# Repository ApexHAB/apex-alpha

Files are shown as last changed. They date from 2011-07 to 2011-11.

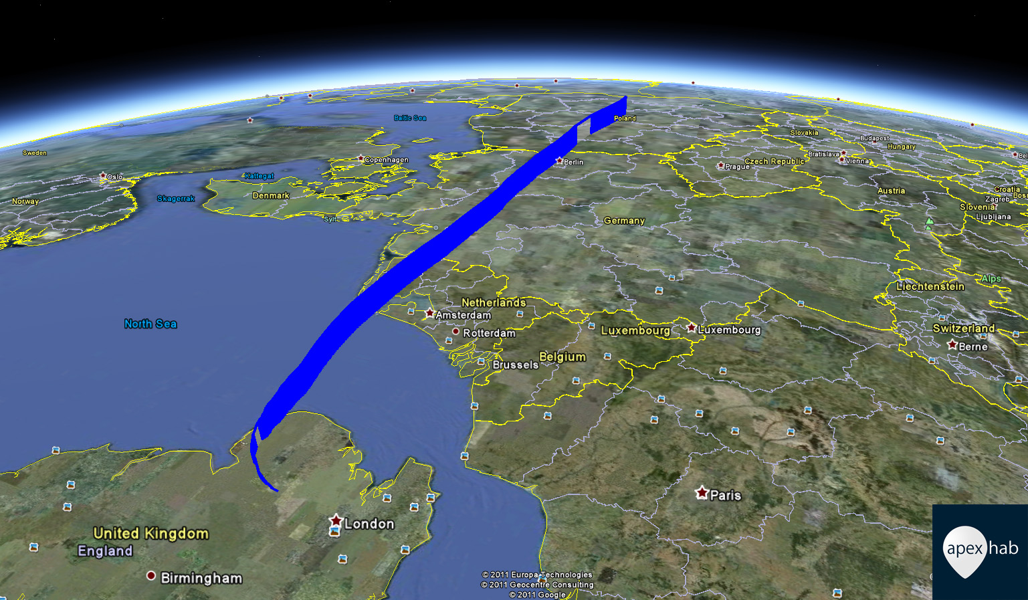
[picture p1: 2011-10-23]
launches/launch-1/maps+graphs/track-3.jpg

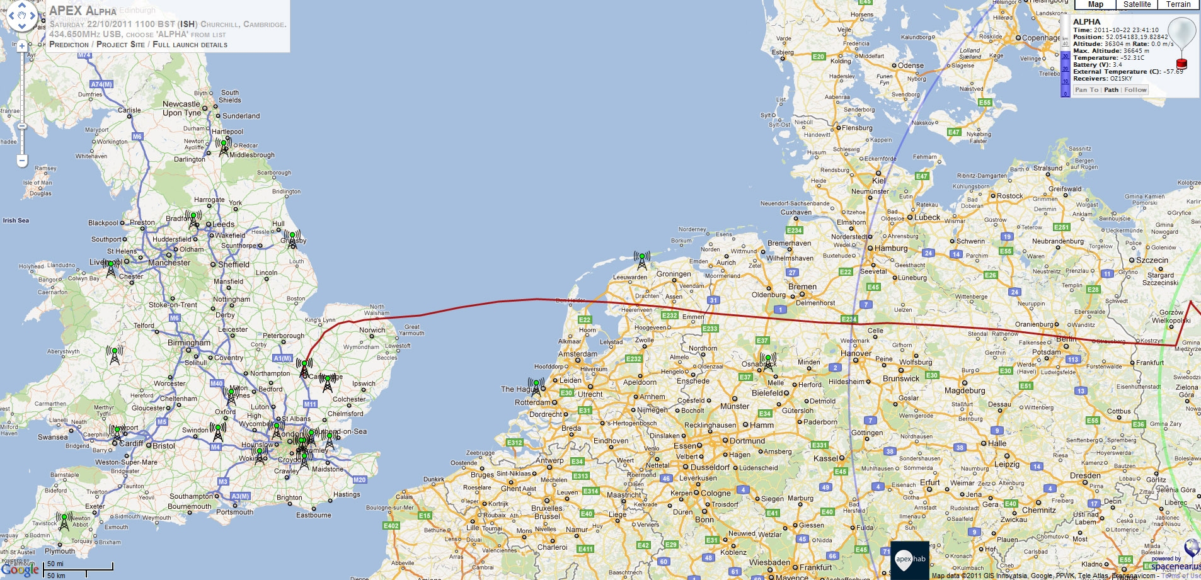
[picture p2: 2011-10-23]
launches/launch-1/maps+graphs/map-2.jpg

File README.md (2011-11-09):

# Apex Alpha
## A small, light-weight payload which will be the predecessor to Apex III

Apex Alpha is a small, light payload which will lead to the development of Apex III. The payload is based around the AVR micro-controllers with the Arduino bootloader. With a completely redesigned payload, we hope that Apex Alpha will be able to help us break records and move the project forward towards Apex III.  Apex Alpha was launched on 22nd October 2011.

## Useful links

* [Homepage](http://www.apexhab.org) - http://www.apexhab.org
* [Apex Alpha Homepage](http://www.apexhab.org/alpha/) - http://www.apexhab.org/alpha/
* [Contact](mailto:team@apexhab.org) - team@apexhab.org
* [Twitter](http://twitter.com/apexhab) - http://twitter.com/apexhab

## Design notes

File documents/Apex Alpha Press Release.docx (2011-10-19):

APEX Alpha High Altitude Balloon Launch by Sutton Grammar School for Boys. Saturday 22nd October 2011. Churchill College, Cambridge.

The APEX team is a group of teenagers who are passionate about electronics, technology and engineering.

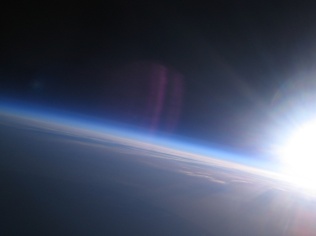
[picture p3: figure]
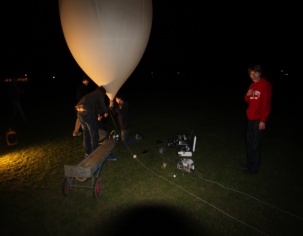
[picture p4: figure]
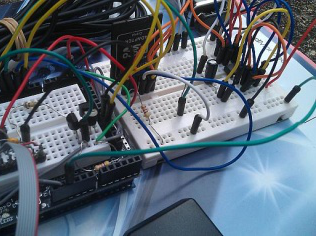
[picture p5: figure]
IMAG0075
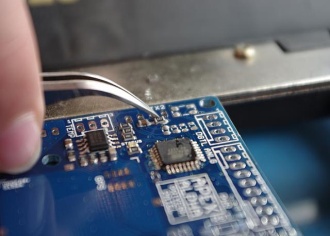
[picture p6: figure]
IMGP1281

Background

The Apex High Altitude Balloon Project aims to use meteorological balloons to take photographs, capture video and collect sensor data from near-space. To date there have been two versions of Apex and three launches in total. On the 22nd October 2011 at 11am there will be a fourth launch with a new, very light payload; the aim is to break the current UK amateur altitude record for a weather balloon flight. Photos of this launch and the team will be available immediately after.

Weather balloons typically reach altitudes of 120,000ft, beyond the troposphere and into the stratosphere; this is 3½ times the altitude of a commercial aeroplane. The ApexHAB team aim to exceed this height and reach 4 times the altitude of a commercial flight.

The Apex High Altitude Balloon Project has been running since September 2008. It is being run by pupils at Sutton Grammar School for Boys. The boys running the project range in age from 15-17 and are named: Priyesh Patel, Daniel Saul, Edward Branford, Philip Warren, Alex Landless, Michael Woodgate and Alex Wakefield.

Launch – Sat 22nd Oct

APEX Alpha, the team’s newest payload will be launched for the first time. Weighing under 275g, it is extremely light with the electronics themselves weighing in at only 36g – sensors on the PCB, designed entirely by the students; include internal and external temperature and GPS co-ordinates and altitude. This data is then relayed to the team via a small radio module which is then picked up on an amateur radio set and fed into a software decoder on the team’s laptops. APEX Alpha is designed to become the core module of our next big payload, APEX III, developed from the ground up to be modular and efficient.

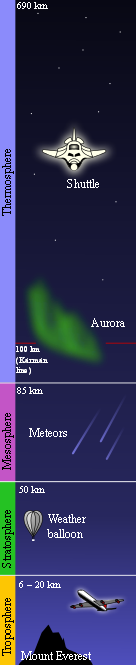
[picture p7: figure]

Funding

The Balloon has been completely self-built by pupils in the school and has been funded by the Institute of Physics, Virgin Galactic, AFCEA (Armed Forces Communications and Electronics Association.), Dorking and District Radio Society, the school’s Curriculum Enrichment Group and the school PTA. The team is once again actively looking for sponsorship.

Previous achievements

Previous launches’ data and photographs are available online at www.apexhab.org including photographs and video footage of sunrise taken above 90,000ft. At this altitude the layers of the Earth’s atmosphere are clearly visible.

Future work

The team will be entering into the National Science and Engineering Competition and hope to gain a place in the finals at the Big Bang Fair in March 2012. There is also another planned launch for Spring 2012 of APEX III carrying instruments capable of measuring radiation levels at varying altitudes, light levels, various gas sensors such as CO2, an ash sensor which could collect interesting data in the event of another volcanic eruption affecting the UK, a pressure sensor, higher resolution cameras and our HD Video Camera.

For more information, please email team@apexhab.org or contact Sutton Grammar School for Boys.

Apex High Altitude Balloon Project press release 19th October 2011 For more information, get in touch at team@apexhab.org

FOR IMMEDIATE RELEASE hab

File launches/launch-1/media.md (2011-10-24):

 * http://ukhas.org.uk/general:flight_data
 * http://ukhas.org.uk/general:uk_records
 * http://hab-howard.blogspot.com/
 * http://arduinoist.com/2011/10/22/apex-alpha-hi-alt-balloon-soars-from-uk-over-germany/
 * http://hackaday.com/2011/10/21/going-for-the-amateur-balloon-altitude-record/
 * http://hackaday.com/2011/10/23/beating-the-wrong-amateur-balloon-record/
 * Sutton Guardian
 * http://apexhab.org/
 * http://science.slashdot.org/story/11/10/23/2330244/uk-team-misses-balloon-altitude-record-but-beats-a-few-others
 * http://ava.upuaut.net/?p=191

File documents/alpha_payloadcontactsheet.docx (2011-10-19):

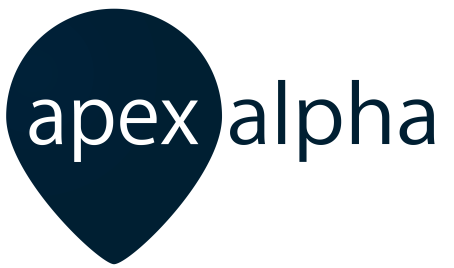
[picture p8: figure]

Harmless Amateur Radio Experiment

By Sutton Grammar School for Boys

Reward for Finding

Please Phone

Daniel +44 (0) 7954 699154

Priyesh +44 (0) 7894 867077

Andrew +44 (0) 7980 354574

Jon +44 (0) 7729 366996

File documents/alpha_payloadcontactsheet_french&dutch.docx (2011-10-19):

Onschadelijk Amateur Radio Experimenteren

Door “Sutton Grammar School for Boys” in het Verenigd Koninkrijk

Beloning voor Bevinding

Stuur een email naar

team@apexhab.org

Dank je wel!

Inoffensif Expérience Radio Amateur

Par “Sutton Grammar School for Boys” au Royaume-Uni

Récompense pour trouver

S'il vous plaît email

team@apexhab.org

Merci!

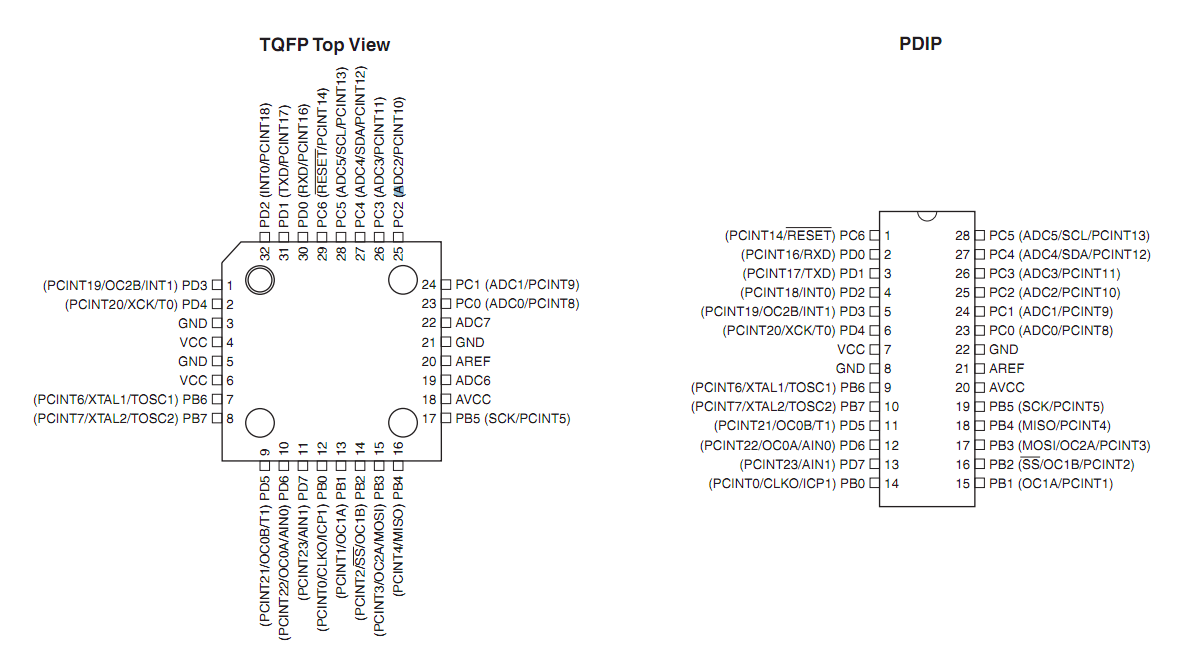
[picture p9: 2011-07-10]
diagrams/avr-pinout.PNG

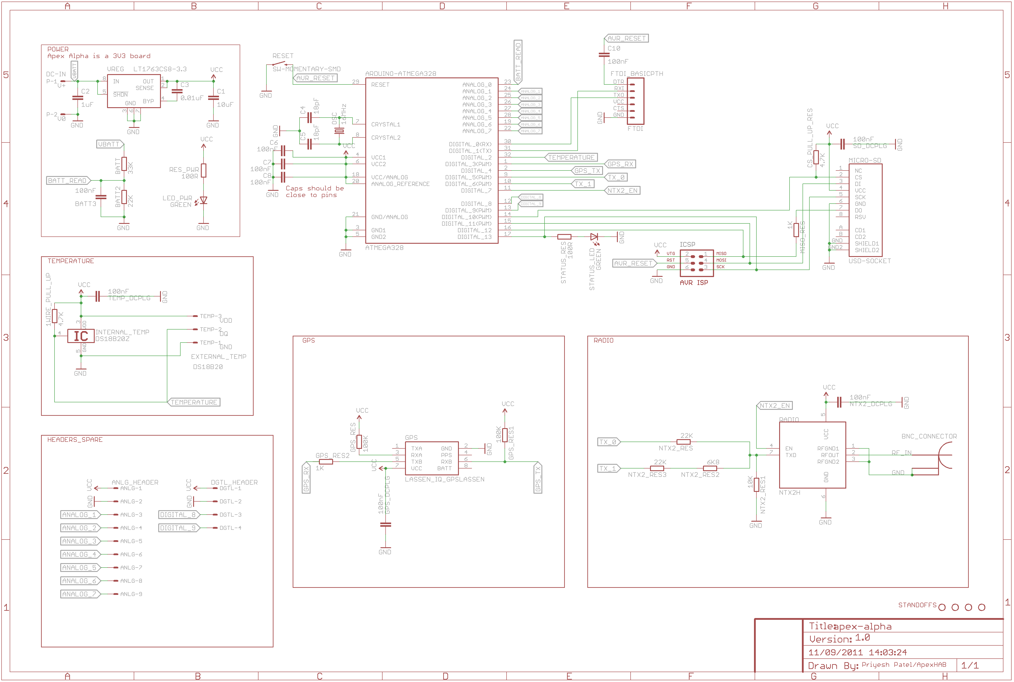
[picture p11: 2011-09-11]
pcb/rev1.0/schematic.png

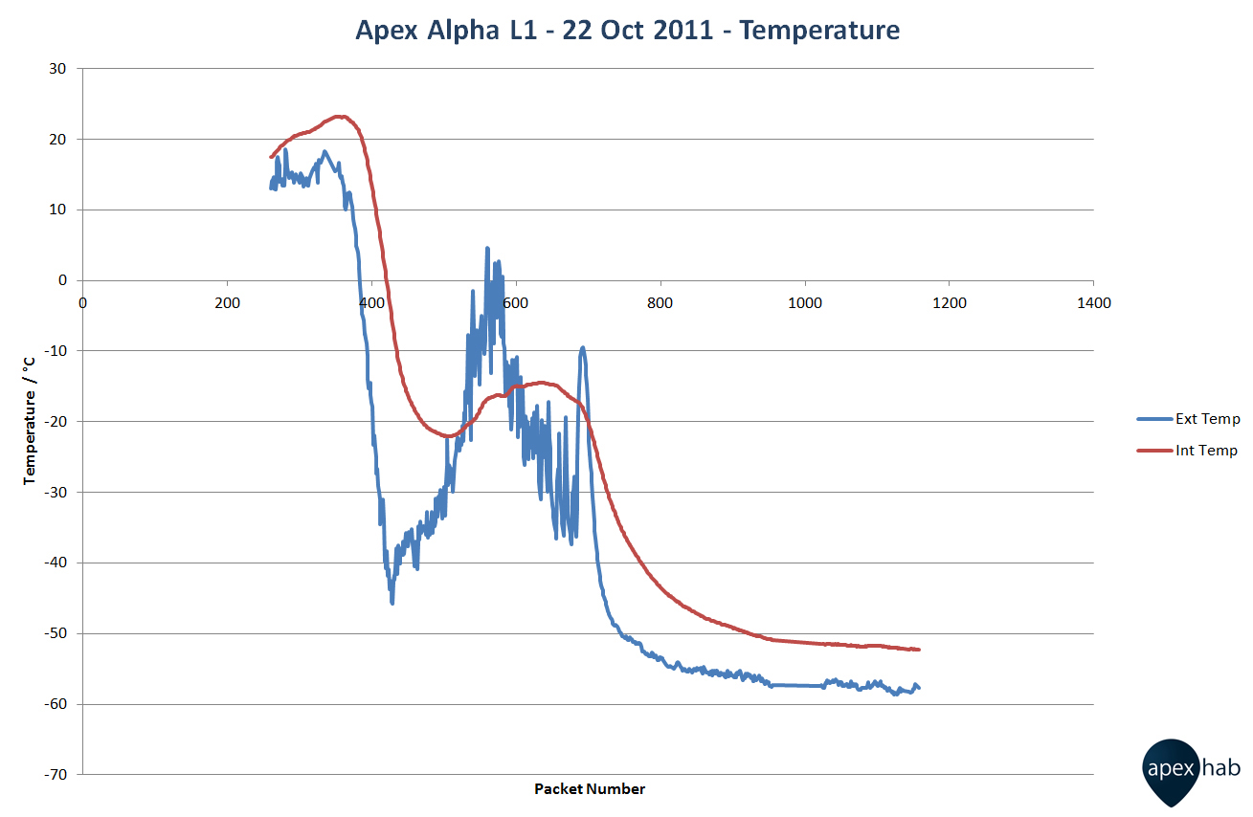
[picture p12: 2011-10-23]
launches/launch-1/maps+graphs/graph-temperature.jpg

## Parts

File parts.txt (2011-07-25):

LINEAR TECHNOLOGY - LT1763CS8-3.3#PBF - V REG LDO +3.3V, SMD, SOIC8, 1763
http://uk.farnell.com/linear-technology/lt1763cs8-3-3-pbf/v-reg-ldo-3-3v-smd-soic8-1763/dp/1273617

HRS (HIROSE) - DM3D-SF - CONNECTOR, MICRO SD, PUSH PULL
http://uk.farnell.com/hrs-hirose/dm3d-sf/connector-micro-sd-push-pull/dp/1764377?Ntt=1764377

TE CONNECTIVITY - 5-1634521-1 - SOCKET, BNC, BULKHEAD, 50R
http://uk.farnell.com/te-connectivity/5-1634521-1/socket-bnc-bulkhead-50r/dp/1248949?Ntt=1248949

2.5mm SMT Momentary PUSH Button
http://iteadstudio.com/store/index.php?main_page=product_info&cPath=10_15&products_id=334

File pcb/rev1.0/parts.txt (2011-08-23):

_________________________________
|    Partlist for Apex Alpha    |
| ============================= |
| http://www.apexhab.org/alpha/ |
|_______________________________|

Part              Value               Device                        Package               Library           Sheet
-----------------------------------------------------------------------------------------------------------------
1WIRE_PULL_UP     4.7K                R-EU_R0603                    R0603                 rcl               1
ANLG              ANLG_HEADER         22-27-2091-09                 6410-09               con-molex         1
ARDUINO-ATMEGA328 ATMEGA328           ATMEGA168-AU                  TQFP32-08             Arduino-AVR       1
BATT              33K                 R-EU_R0603                    R0603                 rcl               1
BATT2             22K                 R-EU_R0603                    R0603                 rcl               1
BATT3             100nF               CAP0805                       0805                  SparkFun          1
C1                10uF                CAP0805                       0805                  SparkFun          1
C2                1uF                 CAP0805                       0805                  SparkFun          1
C3                0.01uF              CAP0805                       0805                  SparkFun          1
C4                18pF                CAP0805                       0805                  SparkFun          1
C5                18pF                CAP0805                       0805                  SparkFun          1
C6                100nF               CAP0805                       0805                  SparkFun          1
C7                100nF               CAP0805                       0805                  SparkFun          1
C8                100nF               CAP0805                       0805                  SparkFun          1
C10               100nF               CAP0805                       0805                  SparkFun          1
CS_PULL_UP_RES    4.7K                R-EU_R0603                    R0603                 rcl               1
DGTL              DGTL_HEADER         22-27-2041-04                 6410-04               con-molex         1
FTDI              FTDI_BASICPTH       FTDI_BASICPTH                 FTDI_BASIC            SparkFun          1
GPS               LASSEN_IQ_GPSLASSEN LASSEN_IQ_GPSLASSEN           LASSEN_IQ_GPS         SparkFun          1
GPS_DCPLG         100nF               CAP0805                       0805                  SparkFun          1
GPS_RES           100K                R-EU_R0603                    R0603                 rcl               1
GPS_RES1          100K                R-EU_R0603                    R0603                 rcl               1
GPS_RES2          1K                  R-EU_R0603                    R0603                 rcl               1
ICSP              AVR-ISP-6           AVR-ISP-6                     AVR-ISP-6             avr-4             1
INTERNAL_TEMP     DS18B20Z            DS18B20Z                      SO08                  1wire             1
LED_PWR           GREEN               LEDCHIPLED_0603               CHIPLED_0603          led               1
MICRO-SD          USD-SOCKET          USD-SOCKET                    MICRO-SD-PUSH-PULL    matt_brejza       1
MISO_RES          1K                  R-EU_R0603                    R0603                 rcl               1
NTX2_DCPLG        100nF               CAP0805                       0805                  SparkFun          1
NTX2_RES          22K                 R-EU_R0603                    R0603                 rcl               1
NTX2_RES1         10K                 R-EU_R0603                    R0603                 rcl               1
NTX2_RES2         6K8                 R-EU_R0603                    R0603                 rcl               1
NTX2_RES3         22K                 R-EU_R0603                    R0603                 rcl               1
OSC               16MHz               CRYSTAL5X3                    CRYSTAL-SMD-5X3       SparkFun          1
P                 DC-IN               22-27-2021-02                 6410-02               con-molex         1
RADIO             NTX2H               NTX2H                         NTX2H                 matt_brejza       1
RESET             SW-MOMENTARY-SMD    SWITCH-MOMENTARY-2-SMD-1101NE TACTILE-SWITCH-1101NE SparkFun          1
RES_PWR           100R                R-EU_R0603                    R0603                 rcl               1
SD_DCPLG          100nF               CAP0805                       0805                  SparkFun          1
STATUS_LED        GREEN               LEDCHIPLED_0603               CHIPLED_0603          led               1
STATUS_RES        100R                R-EU_R0603                    R0603                 rcl               1
TEMP              EXTERNAL_TEMP       22-27-2031-03                 6410-03               con-molex         1
TEMP_DCPLG        100nF               CAP0805                       0805                  SparkFun          1
U$1               BNC_BULK            BNC_BULK                      BNC_BULK              matt_brejza       1
VREG              LT1763CS8-3.3       LT1763CS8-3.3                 SOIC8                 linear-technology 1

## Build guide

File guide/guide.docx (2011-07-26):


the guide

Last Edited 26 July 2011 | www.apexhab.org | © Copyright APEXHAB Team

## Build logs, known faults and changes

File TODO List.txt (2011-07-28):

#################
APEX ALPHA
TODO LIST
#################

Stuff that needs doing now:
--------------------------------------

# Write the guide
# Solder PCB when it comes
# Make / get a case

Should we get into the competition:
--------------------------------------

# Helium Balloons with APEX Alpha Logo on
# Posters with information

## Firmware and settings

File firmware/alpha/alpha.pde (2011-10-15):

/**
 * alpha.pde
 *
 * Part of the Apex Alpha project
 * http://www.apexhab.org/alpha/
 *
 * Priyesh Patel
 *
 * (c) Copyright ApexHAB 2011
 * team@apexhab.org
 */

// Include header files
#include "counter.h"
#include "temperature.h"
#include "gps.h"
#include "rtty.h"
#include "sdlogger.h"
#include "battery.h"

// Define constants (other pin numbers are defined in their respective header files
#define STATUS_LED_PIN 13

// Addresses of sensors
byte ext_temp_addr[8] = {0x28, 0x13, 0xF7, 0x73, 0x03, 0x00, 0x00, 0x2F};
byte int_temp_addr[8] = {0x28, 0x35, 0x8C, 0x5E, 0x03, 0x00, 0x00, 0xDB};

// Define packet variable
char packet[200];

void setup()
{
    // Setup serial
    Serial.begin(9600);

    Serial.println("/------------\\");
    Serial.println("| Apex Alpha |");
    Serial.println("\\------------/");

    // Initialise status LED and then turn it on
    pinMode(STATUS_LED_PIN,OUTPUT);
    digitalWrite(STATUS_LED_PIN,HIGH);

    // Initialise radio module
    rtty_init();

    // System booted
    Serial.println("");
    Serial.println("Apex Alpha successfully booted");
    Serial.println("");

    // Turn status LED off
    digitalWrite(STATUS_LED_PIN,LOW);

    // Blank line to serial
    Serial.println("");
}

void loop()
{
    // Increment the counter
    counter_inc();

    // Get data from external sensors and devices and then construct the packet
    build_packet();

    // Store sent packet and prepare packet
    sprintf(packet,rtty_prepare(packet));

    // Print packet to serial
    Serial.print(packet);

    // Write packet to SD card
    sdlogger_log(packet); 

    // Telemetry
    Serial.print("Telemetry started... ");

    // Send the packet with RTTY
    // @ 300 baud - preamble then 3 times
    rtty_preamble(1);
    rtty_tx("$$ALPHA\r\n", 1);
    rtty_tx(packet, 1);
    rtty_tx(packet, 1);
    rtty_tx(packet, 1);
    // @ 50 baud - preamble then 2 times
    rtty_preamble(0);
    rtty_tx("$$ALPHA\r\n", 0);
    rtty_tx(packet, 0);
    rtty_tx(packet, 0);

    Serial.println("finished");
    
    // Delay until the next packet
    // This window is also for UART commands to be entered in
    delay(4000);

    // Check for any inputted UART commands
    uart_commands();
}
/**
 * Build the packet
 */
void build_packet()
{
    // External temperature sensor
    char et[10];
    dtostrf(temperature_get(TEMPERATURE_PIN,ext_temp_addr),4,2,et);
    // Internal temperature sensor
    char it[10];
    dtostrf(temperature_get(TEMPERATURE_PIN,int_temp_addr),4,2,it);

    // Battery voltage
    char bv[10];
    dtostrf(battery_get_voltage(),4,2,bv);

    // Build the packet
    //sprintf(packet,"$$ALPHA,%u,%s,%s,%s",counter_get(),et,it,bv); // No GPS!
    sprintf(packet,"$$ALPHA,%u,%s,%s,%s,%s",counter_get(),gps_get(),et,it,bv);
}

/**
 * Check for any commands via UART 
 */
void uart_commands()
{
    if(Serial.available() >= 4)
    {
        // A $ signifies the start of a 3 character command
        while((Serial.available() > 0) && (Serial.read() != '$')) {}

        if(Serial.available() >= 3)
        {
            char data[4];
            for(int i=0; i<3; i++)
            {
                data[i] = Serial.read();
            }
            data[3] = 0;
            
            uart_commands_parse(data);
        }
    }

    Serial.flush();
}

/**
 * Parse UART command 
 */
void uart_commands_parse(char* cmd)
{
    if(strcmp(cmd,"RTC") == 0)
    {
        counter_reset();
    }
}

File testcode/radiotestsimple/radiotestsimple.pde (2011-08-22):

 /*
   APEX Alpha - Radio Telemetry Test with 2 Output Pins
   
   Daniel Saul
   Priyesh Patel
   
   18 July 2011

   (C) Copyright APEXHAB Team 2011
   team@apexhab.org
 */

void setup()
{
    pinMode(5,OUTPUT);
    pinMode(6,OUTPUT);

    // Enable NTX2
    pinMode(7,OUTPUT);
    digitalWrite(7,HIGH);
}

void loop()
{
    rtty_tx("$$ALPHA,a,very,long,test,string,is,being,sent,over,rtty!\n");
    delay(2000);
}

void rtty_tx(char * sentence)
{
    // Send a character at a time to the rtty_byte function :P
    char s;

    s = *sentence++;

    while(s != '\0')
    {
        rtty_byte(s);
        s = *sentence++;
    }
}

void rtty_byte(char s){
    // Send a byte at a time to the rtty_bit function

    int b;

    //Send a start bit
    rtty_bit(0);

    //Send rest of it
    for(b=0;b<8;b++)
    {
        if(s & 1)
        {
            rtty_bit(1);
        }
        else
        {
            rtty_bit(0);
        }

        s = s >> 1;
    }

    //Send 2 stop bits
    rtty_bit(1);
    rtty_bit(1);
}

void rtty_bit(int b)
{
    if(b)
    {   // if high
        digitalWrite(6,HIGH);
        digitalWrite(5,LOW);
    }
    else
    {   // if low
        digitalWrite(5,HIGH);
        digitalWrite(6,LOW);
    } 

    delayMicroseconds(3370);
}

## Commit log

2011-07-08 added current consumption txt
2011-07-08 schematic started
    [apex-alpha.sch]
2011-07-10 continued work on schematic
    [apex-alpha.sch]
2011-07-12 more work on apex-alpha schematic
    [apex-alpha.sch]
2011-07-18 completed sdcard + radio
    [apex-alpha.sch]
2011-07-18 schematic completed (gps + headers added) and guide started
    [apex-alpha.sch]
2011-07-18 removed /RESET pull-up and added control for NTX2_EN
    [apex-alpha.sch]
2011-07-19 Fixed radio code. Now all works.
    [radiotest.pde]
2011-07-20 renamed led on schematic
    [apex-alpha.sch]
2011-07-20 added code to find addresses of temp sensors
2011-07-20 added temperature code to firmware
2011-07-20 changes to schematic - added gps_rx resistor and miso_res moved
    [apex-alpha.sch]
2011-07-20 added decoupling capacitors to schematic
    [apex-alpha.sch]
2011-07-20 changed vreg
    [apex-alpha.sch]
2011-07-20 fixed bug with temperature code
2011-07-23 resistor values changed on schematic
    [apex-alpha.sch]
2011-07-23 fixed temperature variable bug
    [alpha.pde]
2011-07-24 put counter/ticker onto EEPROM and introduced UART commands
2011-07-25 pcb started and temp files removed
    [apex-alpha.brd]
2011-07-25 moved files
    [apex-alpha.brd, apex-alpha.sch]
2011-07-25 worked on PCB
    [apex-alpha.brd, apex-alpha.sch]
2011-07-25 more work on pcb
    [apex-alpha.brd]
2011-07-26 changed resistor values for sd card
    [apex-alpha.brd, apex-alpha.sch]
2011-07-27 more work on pcb + added battery voltage sensor
    [apex-alpha.brd, apex-alpha.sch]
2011-07-27 moved decoupling cap on pcb
    [apex-alpha.brd]
2011-07-27 final changes
    [apex-alpha.brd]
2011-07-27 pcb finished + gerbers produced
    [apex-alpha.brd, apex-alpha.sch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]
2011-07-31 added status led code
2011-07-31 moved led code + cleaned up
2011-07-31 fixed typo on schematic
    [apex-alpha.brd, apex-alpha.sch]
2011-09-07 finished battery code - program finished
2011-09-11 adjustments to radio code
    [apex-alpha.brd, apex-alpha.sch]
2011-10-23 added data from l1
    [alpha.xls]
2011-10-23 graphs corrected
    [alpha.xls]
